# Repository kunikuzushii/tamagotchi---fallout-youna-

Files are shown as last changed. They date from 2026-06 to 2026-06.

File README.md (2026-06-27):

# Kaiser Pet 
tamagotchi project for fallout summer 2026
created by Youna Son (≧∇≦)ﾉ

ONSHAPE LINK:

https://cad.onshape.com/documents/d6c669abeeb3d7413e8d21f8/w/bde522f027b95c0c69872acb/e/c43f71f52c280984713279bd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

_________

Kaiser Pet

# What is a Kaiser Pet? 

My custom themed tamagotchi has:
- RBG Screen
- Higher quality pixel art
- Photoresister (light sensor)

and most importantly... ITS FREAKING MICHAEL KAISER!!!

You take care of Kaiser from Blue Lock (animanga) like a standard tamagotchi. For example, you monitor their health, energy, and hunger levels and take care of them accordingly.

Hunger bar too low? 
Feed them!

Energy bar high?
Play with them!

Except it's better because you take care of the goat

______

# Why It Was Made? o((>ω< ))o

I cannot put into words for my love this character. The explanation behind it would likely take up 5 pages on a size 12, Times New Romans, single spaced google document for me to even START talking about it.
ps... you guys should see my embarassing pinterest page of over 300+ pins of Kaiser that made the zine process super easy (Sorry, I'm a pinterest warrior) AND my cosplays

Jokes aside, the main purpose is obviously: ENTERTAINMENT!

With the hype of the World Cup / FIFA, I think taking care of a character based off a soccer animanga would be super cool and fun.
Additionally, I really do want to use this regularly in my life, I love this character to the point where the whole event of fallout might've been an excuse to me building a super sick hardware project that suspiciously caters to my interests

# Pictures (☆▽☆)

CAD image:


Render images (in the zine):





PCB:





Sneak peek of my pixel art!:



______
## Bill of Materials

**Total Cost: $34.33**

| Name | Qty | Unit | Price (USD) | Total (USD) | MOQ | MOQ Price | Source |
| :--- | :---: | :---: | ---: | ---: | :---: | ---: | :--- |
| XIAO ESP32C3 | 1 | pcs | $4.99 | $4.99 | 1 | $4.99 | [Order](https://www.seeedstudio.com/Seeed-XIAO-ESP32C3-p-5431.html) |
| XHXDZ 1207-P6.5MM Buzzer | 1 | pcs | $0.50 | $5.03 | 10 | $5.03 | [Order](https://www.aliexpress.us/item/3256810135642750.html) |
| HS180S10B Screen | 1 | pcs | $3.21 | $3.21 | 1 | $3.21 | [Order](https://www.lcsc.com/product-detail/C5329585.html) |
| RC0805FR-0710KL Resistor | 1 | pcs | $0.10 | $0.10 | 1 | $0.10 | [Order](https://www.digikey.com/en/products/detail/yageo/RC0805FR-0710KL/727535) |
| GL12528 LDR | 1 | pcs | $0.31 | $1.56 | 5 | $1.56 | [Order](https://www.lcsc.com/product-detail/C559386.html) |
| M20-9990246 Connector | 1 | pcs | $0.10 | $0.10 | 1 | $0.10 | [Order](https://www.digikey.com/en/products/detail/harwin-inc/M20-9990246/3728226) |
| TSC016A04518A Tactile Switch | 3 | pcs | $0.01 | $0.54 | 50 | $0.54 | [Order](https://www.lcsc.com/product-detail/C2888493.html) |
| Battery | 1 | pcs | $6.20 | $6.20 | 1 | $6.20 | [Order](https://www.aliexpress.us/item/3256808658204287.html) |
| PCB | 1 | pcs | $0.40 | $2.00 | 5 | $2.00 | [Order](https://jlcpcb.com) |
| PLA Housing | 1 | pcs | - | - | - | - | Self-Print / Local |
| M3 x 10mm Socket Cap Head Screws | 3 | pcs | $0.47 | $1.88 | 4 | $1.88 | [Order](https://accu-components.com/us/metric-cap-head-screws/16004-SSCF-M3-10-12-9) |
| M3 x 5mm Socket Cap Head Screws | 5 | pcs | $0.31 | $1.86 | 6 | $1.86 | [Order](https://accu-components.com/us/metric-cap-head-screws/16001-SSCF-M3-5-12-9) |
| TS-107-T-AA Connector | 2 | pcs | $1.28 | $2.56 | 1 | $1.28 | [Order](https://www.digikey.com/en/products/detail/samtec-inc/TS-107-T-AA/10218878) |
| TS-110-T-A Connector | 2 | pcs | $ 2.15 | $4.30 | 1 | $2.15 | [Order](https://www.digikey.com/en/products/detail/samtec-inc/TS-110-T-A/1105484) |
Total Cost (USD) is the REAL price required before shipping fees
____

# BUILD & ASSEMBLY
___
# Required Tools
___
1) Solder
2) Sldering iron
3) Tweezers
4) 3D Printer
5) Screwdriver for M3 5mm & M3 10mm Screws
6) Electronic device to connect to tamagotchi through USB port

# Assembly Directions
____
1) Solder the Seeed Studio XIAO ESP32-C3, OLED display header connections, tact switches, battery connector, and all remaining through-hole and surface-mount components onto the PCB FOLLOWING the schematic/layout
2) Check for incomplete connections.
3) Press the buttons down until they fit. 
5) Route the battery leads to cable path and place the lipo battery into the battery compartment right below the pcb or just look under.
6) Solder/connect the battery to the PCB battery connector. Check for polarity!
7) Align PCB assembly with the mounting posts inside the bottom case and SLOWLY put it into place. 
8) Secure the PCB to the bottom case using 3× M3 mounting screws, tightening them evenly. Please focus on tightening them properly before it just falls out. (haha, falls out like. fallout. haha)
9) Verify that it aligns again. This is super important!
10) Position the top case onto the bottom case.
11) Fasten the enclosure halves together using the specified M1.6 screws, tightening each screw gradually in an alternating pattern to ensure even clamping.
12) Install all the software libraries in Arduino.
13) Connect the XIAO ESP32-C3 to a computer using a USB-C cable and select the correct board and COM port within the Arduino IDE.
14) Compile firmware! Check everything including error messages (shouldn't be any).
bonus - since my sprites are in a separate file due to the upgraded OLED, you can easily change up the sprites to whatever you want as long as you edit the kaiser_sprites.h properly
15) Upload the firmware to the ESP32-C3, make sure you get the completion message.
16) Turn it on or off to check if it connects properly especially without USB connection.
17) Test the OLED if it renders my beautiful pixel art properly + status bar. 
18) Test all button inputs, you can manipulate the button functions off the firmware if you really want to.
19) Confirm everything else: charging, functioning, missing pixels, etc.

Congrats! I hope someone can actually enjoy this and build it for themselves!

# CREDITS:
- ONSHAPE (for CAD)
- KiCAD (all hardware / PCB stuff)
- Fallout

LIBRARIES CREDITS
## Dependencies
You need these libraries (add to Arduino libraries managers)
* **Adafruit GFX Library** (by Adafruit)
* **Adafruit ST7735 and ST7789 Library** (by Adafruit)
* **SPI** (Built-in to Arduino IDE)

# PIXEL ART AND ZINE CREDITS
REFERENCES AND INSPIRATION (Pinterest!) :

- https://www.pinterest.com/pin/168322104817334436/
- https://www.pinterest.com/pin/888123989041302114/
- https://www.pinterest.com/pin/114560384269168373/
- https://www.pinterest.com/pin/888123989035366728/
- https://www.pinterest.com/pin/888123989035906915/
- https://pin.it/148EMhVAn
- https://share.google/kxDoDrVdniUi0Naia
- https://pin.it/6CnxexgHx

and obviously, kudos to Muneyuki Kaneshiro for making my favorite character and Yusuke Nomura for bringing him to life by drawing him.

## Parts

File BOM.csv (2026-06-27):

KAISER PET BILL OF MATERIALS
Total Cost
$ 34.33
Name | Qty | Unit | Price (USD) | Total (USD) | MOQ | MOQ Price | Source
XIAO ESP32C3 | 1 | pcs | $ 4.99 | $4.99 | 1 | $4.99 | https://www.seeedstudio.com/Seeed-XIAO-ESP32C3-p-5431.html
XHXDZ 1207-P6.5MM Buzzer | 1 | pcs | $ 0.50 | $5.03 | 10 | $5.03 | https://www.aliexpress.us/item/3256810135642750.html
HS180S10B Screen | 1 | pcs | $ 3.21 | $3.21 | 1 | $3.21 | https://www.lcsc.com/product-detail/C5329585.html
RC0805FR-0710KL Resistor | 1 | pcs | $ 0.10 | $0.10 | 1 | $0.10 | https://www.digikey.com/en/products/detail/yageo/RC0805FR-0710KL/727535
GL12528 LDR | 1 | pcs | $ 0.31 | $1.56 | 5 | $1.56 | https://www.lcsc.com/product-detail/C559386.html
M20-9990246 Connector | 1 | pcs | $ 0.10 | $0.10 | 1 | $0.10 | https://www.digikey.com/en/products/detail/harwin-inc/M20-9990246/3728226
TSC016A04518A Tactile Switch | 3 | pcs | $ 0.01 | $0.54 | 50 | $0.54 | https://www.lcsc.com/product-detail/C2888493.html
Battery | 1 | pcs | $ 6.20 | $6.20 | 1 | $6.20 | https://www.aliexpress.us/item/3256808658204287.html
PCB | 1 | pcs | $ 0.40 | $2.00 | 5 | $2.00 | https://jlcpcb.com
PLA Housing | 1 | pcs | - | - | - | - | Self-Print / Local
M3 x 10mm Socket Cap Head Screws | 3 | pcs | $ 0.47 | $1.88 | 4 | $1.88 | https://accu-components.com/us/metric-cap-head-screws/16004-SSCF-M3-10-12-9
M3 x 5mm Socket Cap Head Screws | 5 | pcs | $ 0.31 | $1.86 | 6 | $1.86 | https://accu-components.com/us/metric-cap-head-screws/16001-SSCF-M3-5-12-9
TS-110-T-A Connector | 2 | pcs | $ 2.15 | $4.30 | 1 | $2.15 | https://www.digikey.com/en/products/detail/samtec-inc/TS-110-T-A/1105484
TS-107-T-AA Connector | 2 | pcs | $ 1.28 | $2.56 | 1 | $1.28 | https://www.digikey.com/en/products/detail/samtec-inc/TS-107-T-AA/10218878

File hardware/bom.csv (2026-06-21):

Name | Qty | Unit | Price (USD) | Total (USD) | MOQ | MOQ Price | Source
Seeed Studio XIAO ESP32 C3 | 1 | pcs | 8.49 | 8.49 | 1 | 8.49 | https://www.aliexpress.us/item/3256808047100037.html
1.8 inch TFT LCD 128x160 | 1 | pcs | 7.13 | 7.13 | 1 | 7.13 | https://jlcpcb.com/partdetail/HS-HS280S010B/C2939938
Piezo Buzzer | 1 | pcs | 0.50 | 0.50 | 10 | 5.02 | https://www.aliexpress.us/item/3256810135642750.html
Tactile Buttons | 3 | pcs | 0.23 | 0.68 | 10 | 2.25 | https://www.aliexpress.us/item/3256807067168626.html
M3 5mm Screws | 5 | pcs | 0.04 | 0.19 | 50 | 1.92 | https://www.aliexpress.us/item/2251832785290389.html
M3 10mm Screws | 3 | pcs | 0.05 | 0.14 | 50 | 2.34 | https://www.aliexpress.us/item/2251832785290389.html
Battery | 1 | pcs | 5.16 | 5.16 | 1 | 5.16 | https://www.aliexpress.us/item/3256808658204287.html
PCB | 1 | pcs | 0.40 | 0.40 | 5 | 2.00 | https://jlcpcb.com
PLA 3D Printed Case | 1 | pcs | - | - | - | -
Total | 17 | - | - | 22.69 | - | 34.31 | -

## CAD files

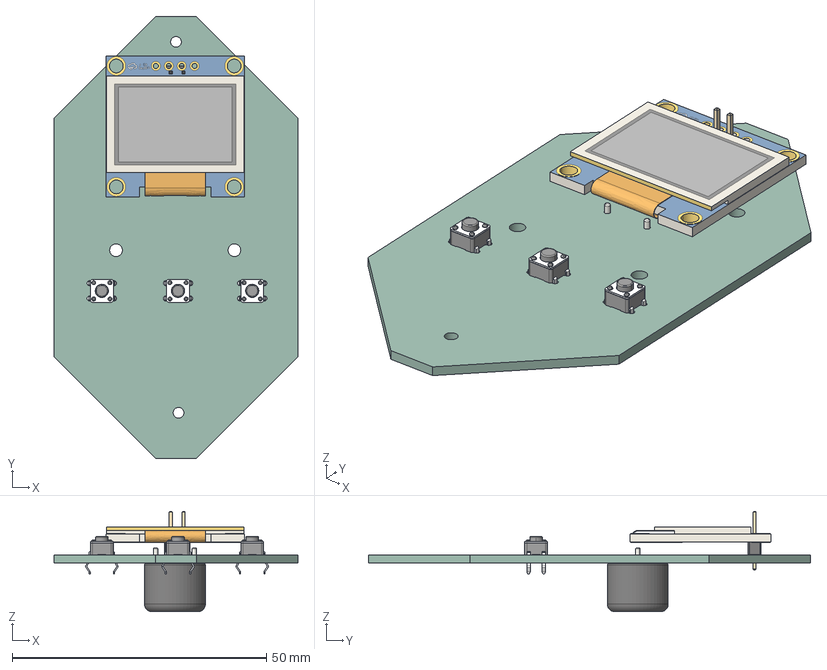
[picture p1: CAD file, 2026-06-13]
.step
48.0 x 87.0 x 19.8 mm
PinHeader_1x02_P254mm_Vertical
OLED-TH_L27.8-W27.2-P2.54_C9900033791
Buzzer_12x95RM76
tamagotchi_PCB

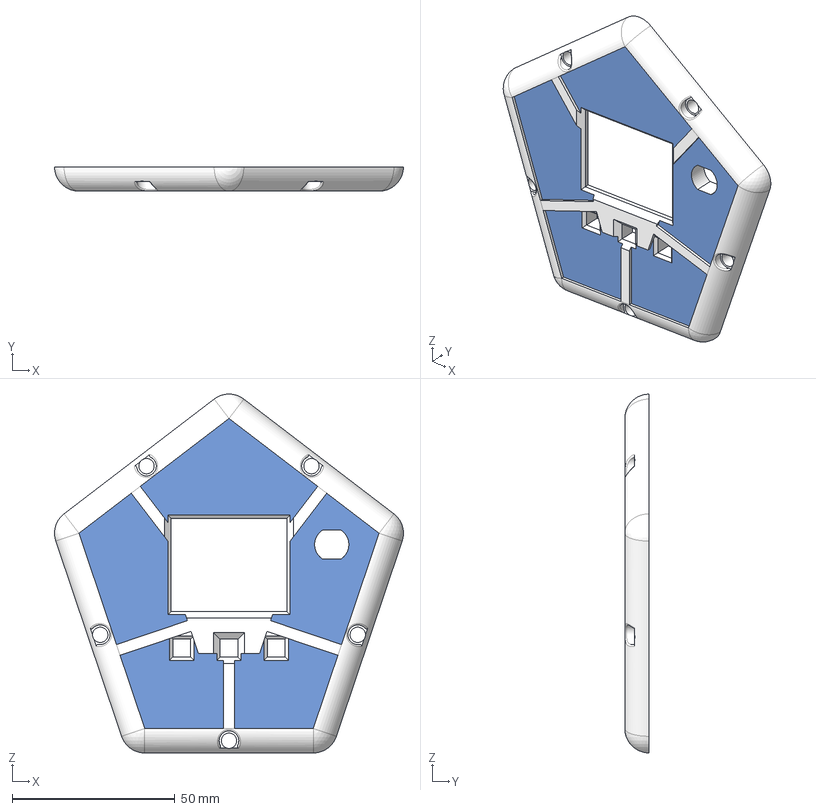
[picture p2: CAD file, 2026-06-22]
CAD/topcase.step
107.1 x 7.50 x 110.1 mm

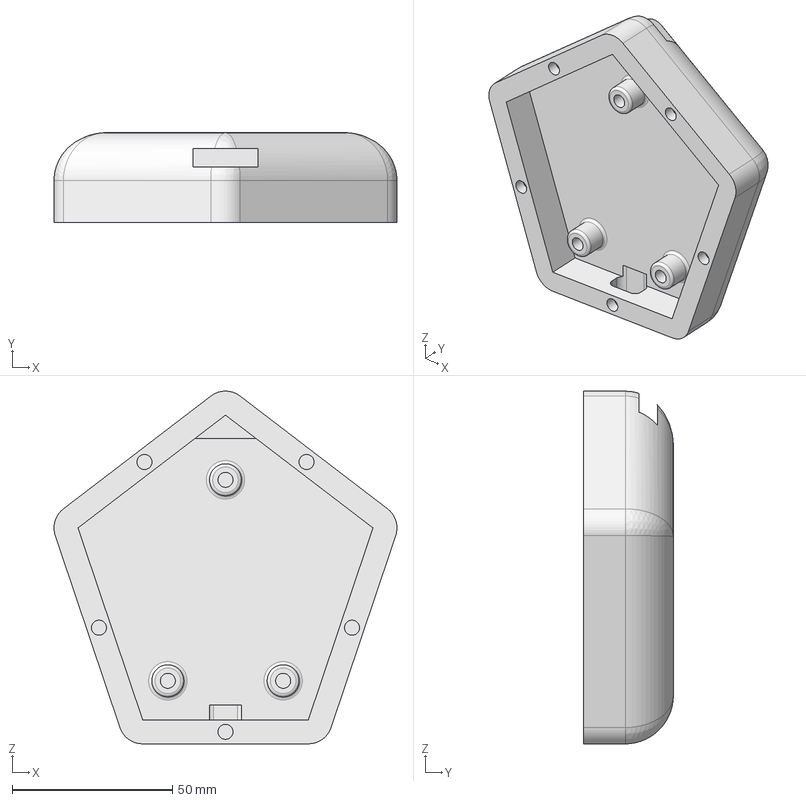
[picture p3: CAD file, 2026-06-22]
CAD/bottomcase.step
107.1 x 28.0 x 110.1 mm

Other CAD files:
hardware/kiCad/.step
PCB Files/.step
CAD/bottomcase.3mf
CAD/topcase.3mf

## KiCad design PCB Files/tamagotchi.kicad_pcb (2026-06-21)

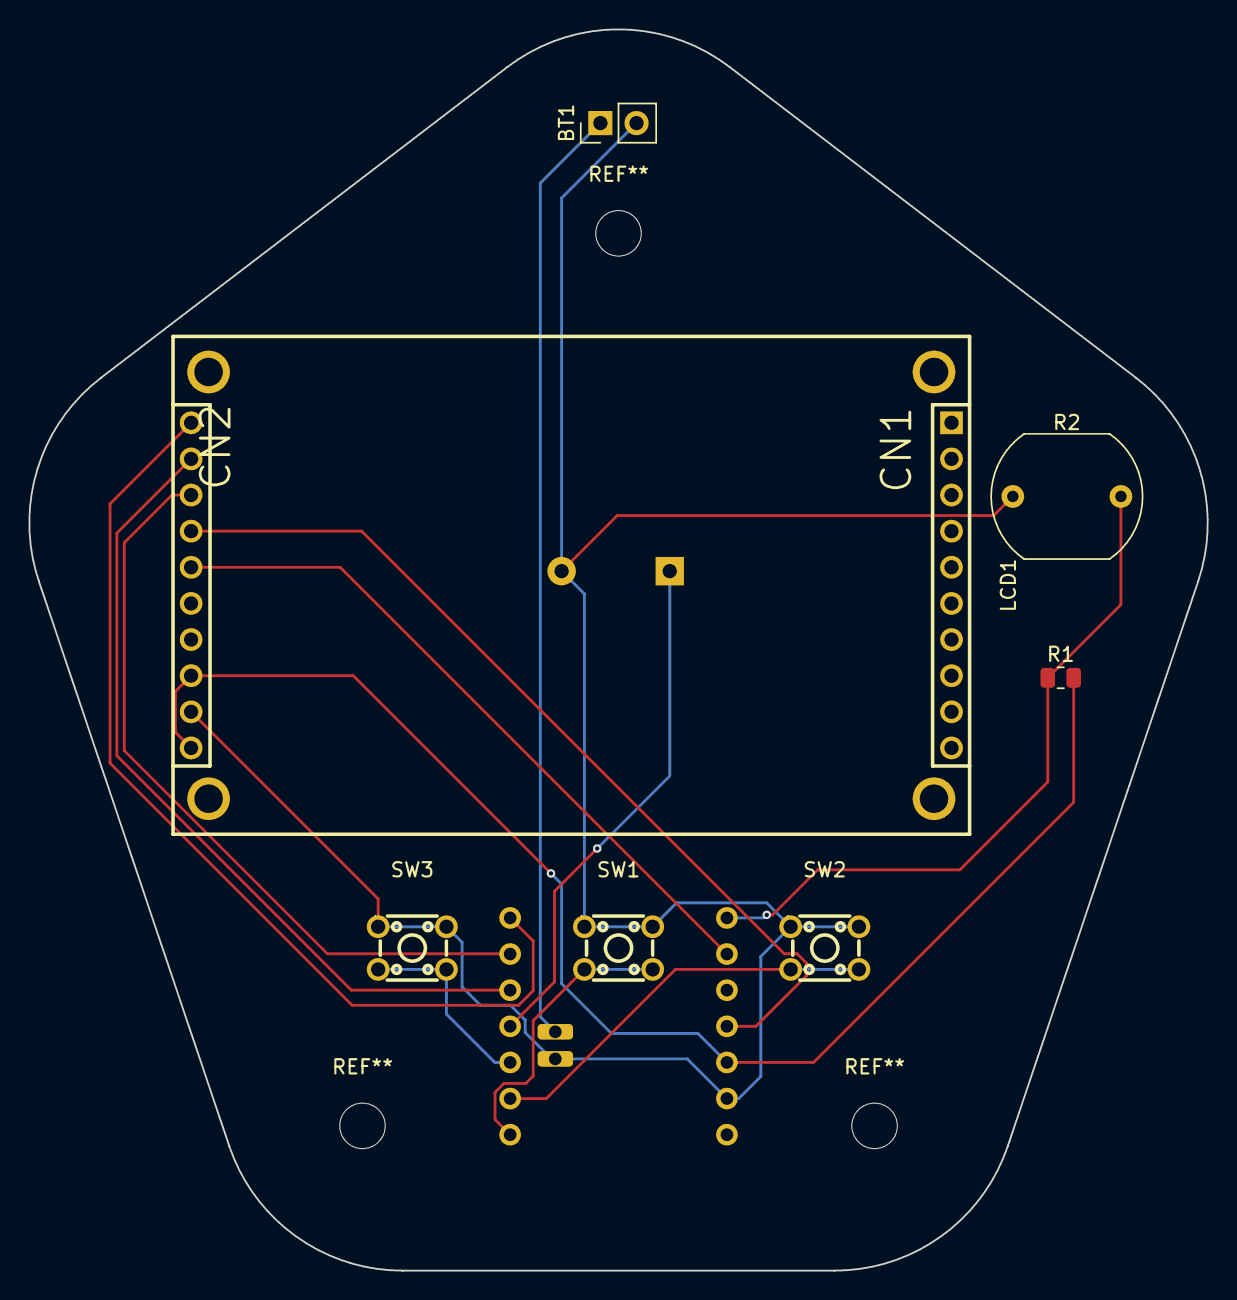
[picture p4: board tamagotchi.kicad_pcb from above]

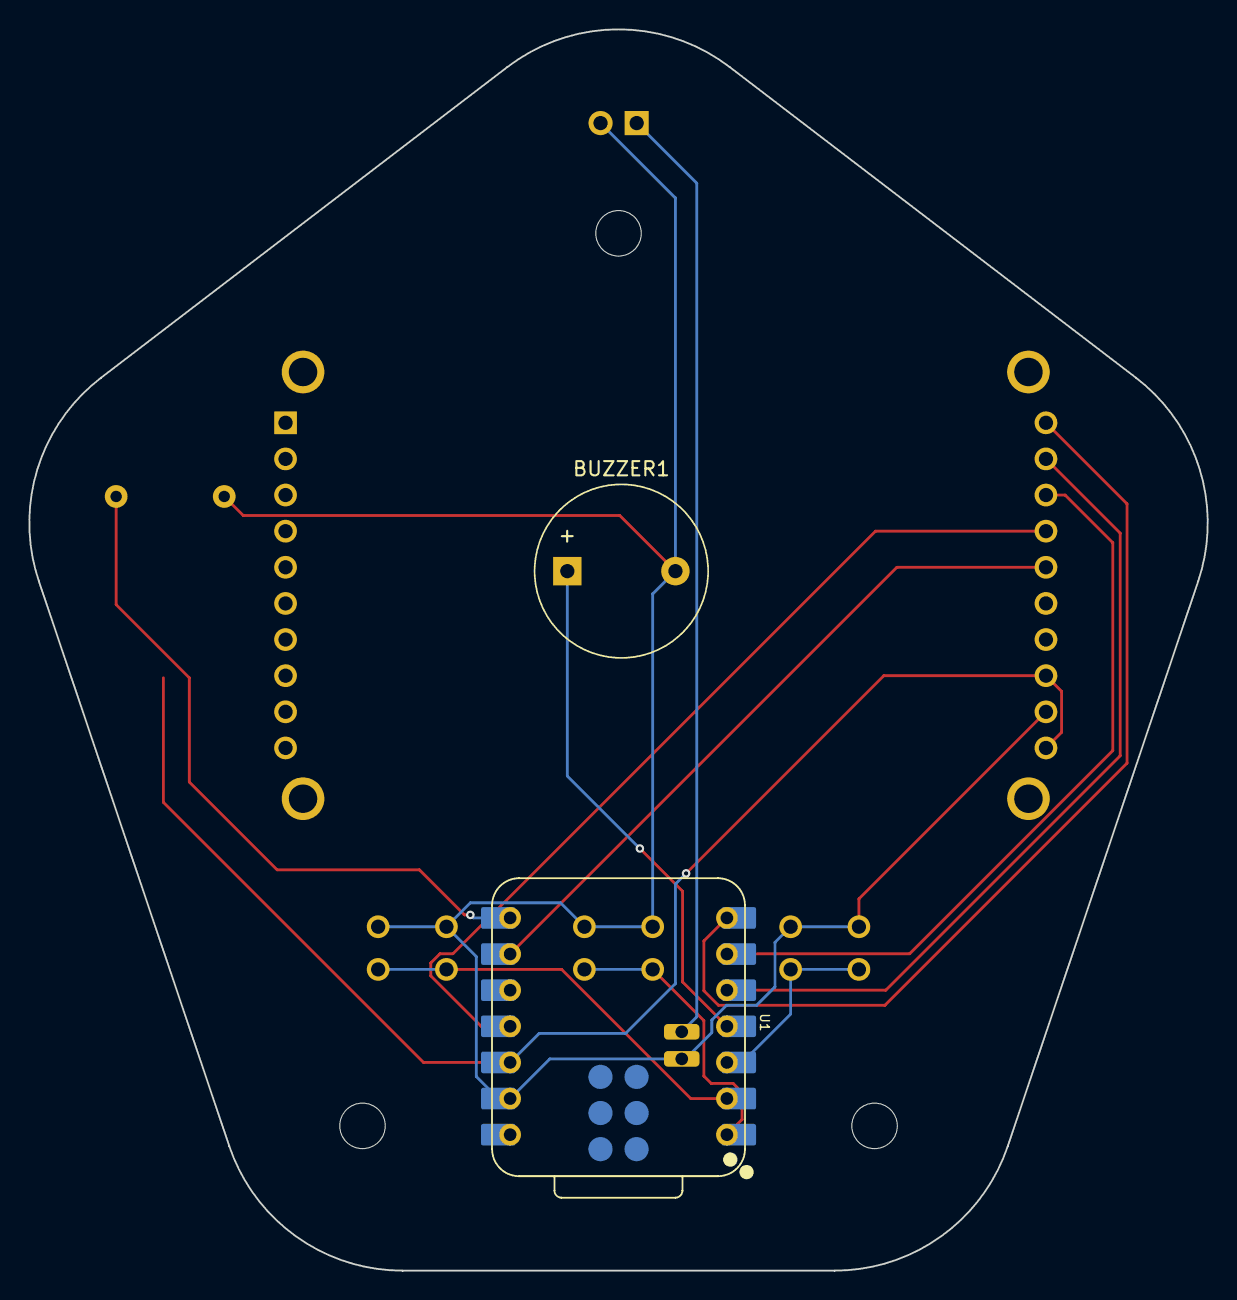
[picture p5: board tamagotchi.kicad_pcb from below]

Board: 2 copper layers, 82.8 x 87.3 mm, 9 parts (2 on the bottom side), 13 nets.

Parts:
BT1: Battery_Cell; PinHeader_1x02_P2.54mm_Vertical
BUZZER1: 1207-P6.5MM; Buzzer_12x9.5RM7.6
LCD1: HS180S10B; LCD-TH_L56.0-W35.0-P2.54_HS180S10B
R1: 10k; R_0805_2012Metric
R2: LDR03; R_LDR_10x8.5mm_P7.6mm_Vertical
SW1, SW2, SW3: SW_Push; SW-TH_4P-L4.5-W4.5-P3.00-LS4.8
U1: XIAO-ESP32-C3-SMD; XIAO-ESP32-C3-DIP-SMD

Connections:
+3V3: LCD1.11, LCD1.13, R1.2, U1.12 (3V3)
+BATT: BT1.1 (+), U1.15
/CS1: LCD1.20, U1.7 (GPIO21_D6_TX)
/DC: LCD1.18, U1.6 (GPIO7_D5_SCL)
/RES: LCD1.19, U1.5 (GPIO6_D4_SDA)
GND: BT1.2 (-), BUZZER1.2 (-), LCD1.12, R2.1, SW1.1, SW2.1, SW3.1, U1.13 (GND), U1.16
unnamed: BUZZER1.1 (+), U1.4 (GPIO5_A3_D3)
unnamed: SW1.2, U1.1 (GPIO2_A0_D0)
unnamed: SW2.2, U1.2 (GPIO3_A1_D1)
unnamed: SW3.2, U1.3 (GPIO4_A2_D2)
unnamed: LCD1.16, U1.9 (GPIO8_D8_SCK)
unnamed: LCD1.17, U1.11 (GPIO10_D10_MOSI)
unnamed: R1.1, R2.2, U1.8 (GPIO20_D7_RX)

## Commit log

2026-06-21 Add BOM.csv with bill of materials details
    [BOM.csv]
2026-06-21 Add components and pricing to BOM CSV
    [bom.csv]
2026-06-25 file name change
    [.step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]
2026-06-27 name change
    [BOM.csv]
2026-06-27 Revise README with project updates and assembly details
    Updated project details, added images, and revised assembly instructions.
